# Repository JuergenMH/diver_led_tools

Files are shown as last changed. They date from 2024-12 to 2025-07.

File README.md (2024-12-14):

# diver_led_tools
This repository contains two projects or units.

The first one is a LED "Diver marker" and the second one is "Diver flasher".
Both devices are tools for scuba drivers.
It shares some ressources, this was the reason to put them into one repository.

## Folders
    2D drawings:            brainstorming folder with ideas how to create possible water proofed housings for the diver marker/flasher.
    documents:              different documents regarding both units.
    Firmware_diver_flasher: currently a copy of an older project which will be the base for the new software
    FIrmware_diver_marker:  ditto
    Pcb_Diver_Marker:       Eagle (7.6) PCB for this unit
    Pcb_Diver_Flasher:      KiCAD (8.0) PCB for this unit
    SKEDD-PIC-Cable:        KiCAD (8.0) schematic for the connection cable PICKIT <> PCB for program and debug purposes

## Current state (14.12.2024)
The folder structures and content are still under construction!

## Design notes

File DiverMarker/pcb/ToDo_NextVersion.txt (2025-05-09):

+/- der LEDs sind aktuell vertauscht und teilweise auf falschen Layern

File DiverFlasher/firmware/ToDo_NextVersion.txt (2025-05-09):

MOSFET 2mm in Richtung Batteriehalter schieben
Auf Unterseite + und - im Ausschnitt des Batteriehalters auf den Bottom Silkscreen
Beim Spulen-Footprint die Pads ca. 2mm nach außen setzen (leichtere Lötbarkeit)

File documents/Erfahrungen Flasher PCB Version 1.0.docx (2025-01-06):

# Erfahrungen mit der ersten PCB-Version

## Funktion

Die Leiterkarte funktioniert grundsätzlich, aber die emittierte Lichtmenge ist nicht überzeugend.

Die 5V-Spannung zur Versorgung der LEDs bricht beim Blitz auf einen Wert von ca. 4,5V ein und der LED-Strom liegt um 350mA an Stelle der erwarteten 1A.

Achtung: Im Schaltplan waren 1W LEDs eingetragen. Es gibt sie in der gleichen Bauform auch als 3W Typen. Zu prüfen ist, was bestellt und was demzufolge bestückt wurde.

Das hat zwei Ursachen:

1. Die im Pufferkondensator (470µF) gespeicherte Energie reicht bei weitem nicht aus, die erforderlichen 50ms zu puffern. Selbst bei einer parallelgeschalteten Kapazität von 1000µF ergibt sich keine deutliche Verbesserung. => Erhöhung der Kapazität nicht erfolgversprechend.
2. Der Boost-Konverter liefert nur einen Strom von ca. 0,5 A und das reicht nicht aus, um die Spannung am Ladekondensator zu halten. Reicht noch nicht einmal für 1W LEDs …

Folgende Maßnahmen wurde erfolglos geprüft:

- Erhöhung der Booster-Spannung auf 6V => messbare, aber nicht sichtbare Wirkung
- 1Ohm LED-Vorwiderstand reduziert über 0,33, 0,18 auf 0Ohm (420mA) => schwacher Effekt sichtbar.
- Verlängerung der Blitzdauer auf 75ms => schwacher Effekt sichtbar Darüber hinaus wird der Blitz länger, aber nicht heller

Fazit: Die Schaltung muss überarbeitet werden!

## Library/Footprints

Beim Batteriehalter haben die Bohrungen der beiden dicken Bolzen einen viel zu kleinen Durchmesser; beim Prototyp wurden 3,5mm gebohrt; das hat funktioniert.Es gibt noch einen dritten Bolzen, der ein Verdrehen verhindert. Dieser Bolzen fehlt komplett.

Für die Elkos wurden falsche Footprints ausgewählt.

Fazit: Footprint Batteriehaltermuss korrigiert werden!
Für die Elkos Footprint „eine Nummer größer“ wählen

## Sonstige Themen

Der Batteriehalter ist für ungeschützte 18650 Zellen ausgelegt; bestellt wurden aber geschützte Zellen. Diese sind ca. 3mm länger, als ungeschützte und passen nur mit Gewalt in den Halter.

- Ungeschützte Zellen bestellen

Der SKEDD-Stecker kann nicht eingesteckt werden, wenn die Batterie vollständig in den Halter eingelegt ist. Nicht perfekt, aber akzeptabel.

- Nicht perfekt, aber akzeptabel

Die 470µF Elkos bauen relativ hoch auf. Zwei Optionen sind denkbar: Mehrere kleinere Kondensatoren parallel oder die „dicken“ LEDs auf die Seite der Batterie verlegen. In diesem Fall wird die Platine größer.
Allerdings: Wenn eine Seite der Platine flach gestaltet würde, und die Platine nicht in der Mitte des Gehäuses säße, wären auch die LEDs nicht mehr in der Mitte der Lichtkuppel => macht wenig Sinn.

- Bei den Arbeiten am Booster, dieses Thema bearbeiten; keine hohe Priorität.

Zusammenfassung / Übersicht über die Punkte:

- LEDs sind möglicherweise falsch; geplant waren 3W; eingesetzt wurden ggf. nur 1W LEDs
- Geschützte Batterie passt nicht gut in die Fassung
- Die erste Schaltung bringt rund 2*1W und das ist nicht sonderlich hell
- Vermutlich wäre ein mit 3,3V schaltender N-MOSFET günstiger als der gewählte NPN-Darlington.

Mögliche Lösungen:

Ende des Dokuments.

PCB Diver Flasher Version 1.0

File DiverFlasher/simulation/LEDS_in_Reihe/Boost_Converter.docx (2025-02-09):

Kurvenformen

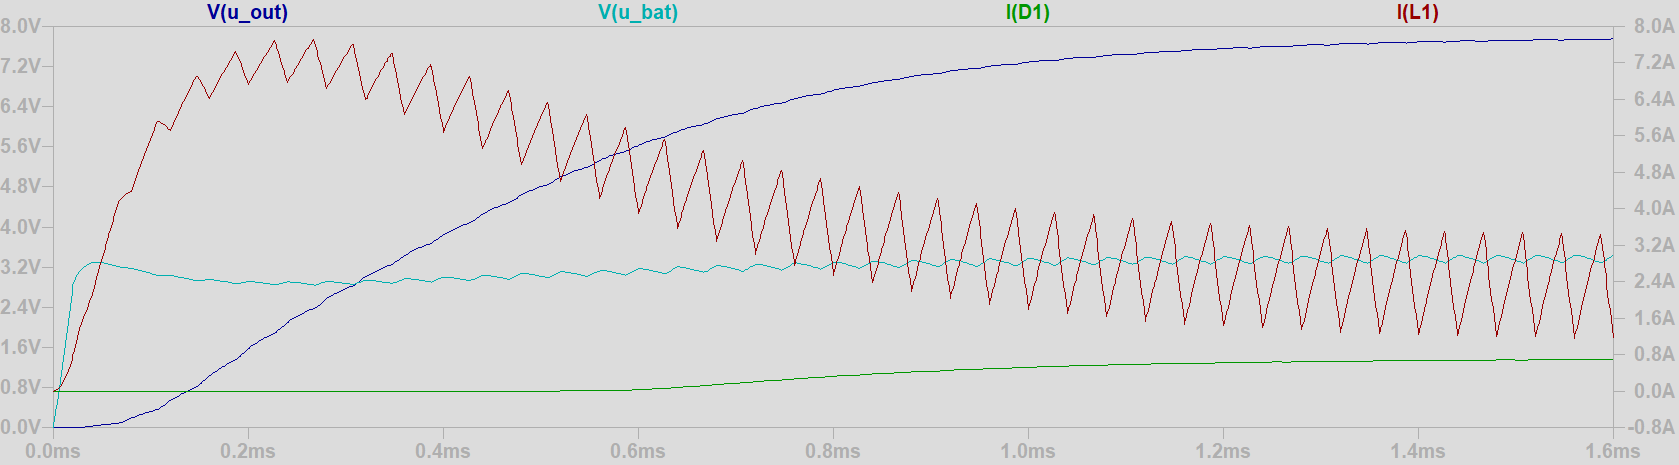
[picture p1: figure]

Schaltung

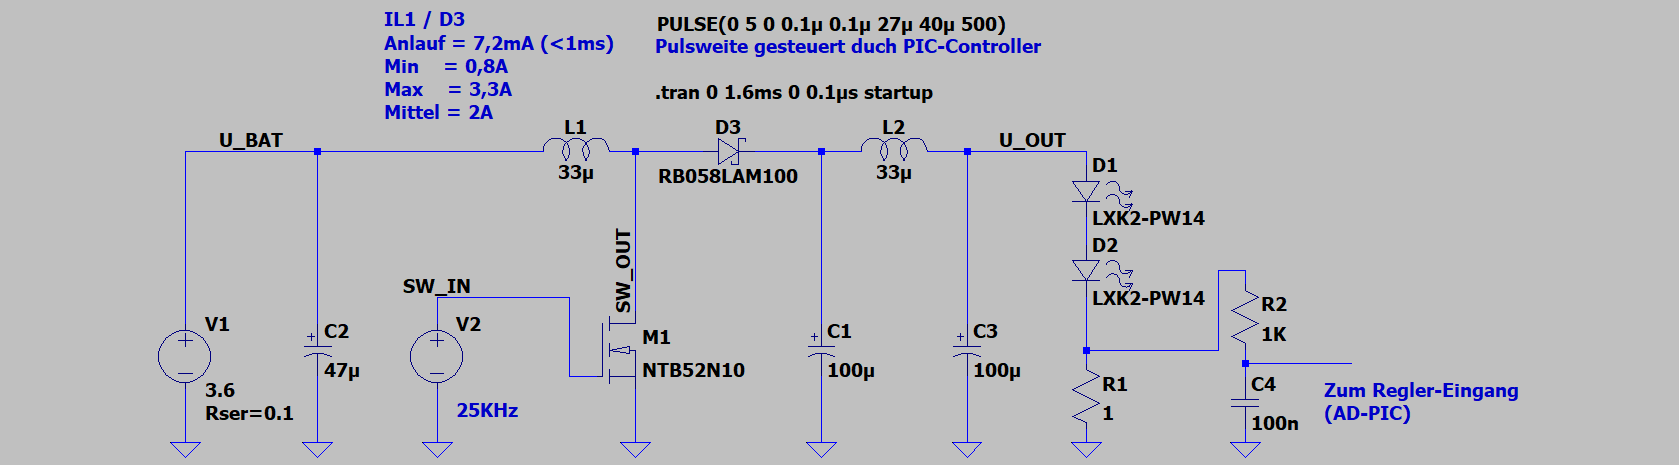
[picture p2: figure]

Boost Converter mit LEDs in Reihe

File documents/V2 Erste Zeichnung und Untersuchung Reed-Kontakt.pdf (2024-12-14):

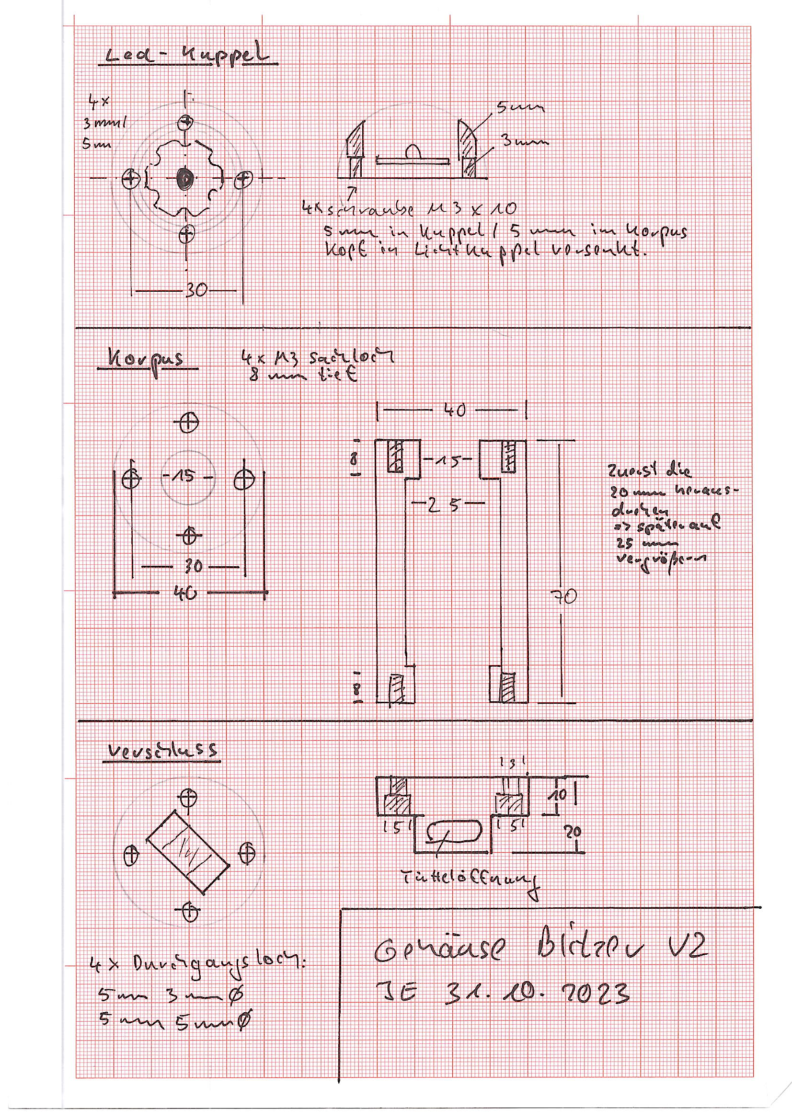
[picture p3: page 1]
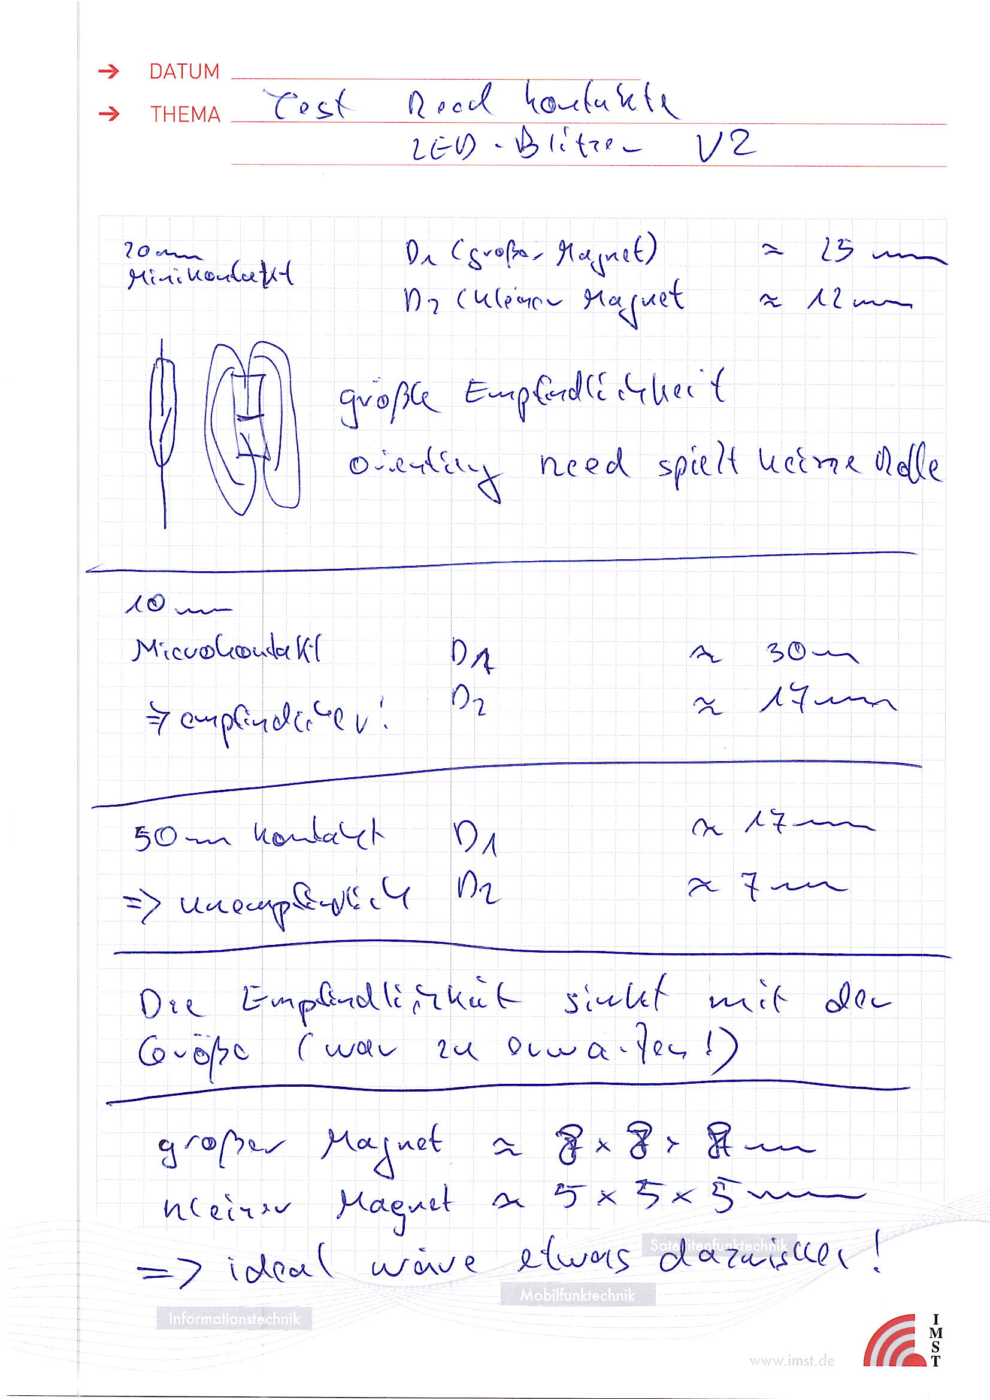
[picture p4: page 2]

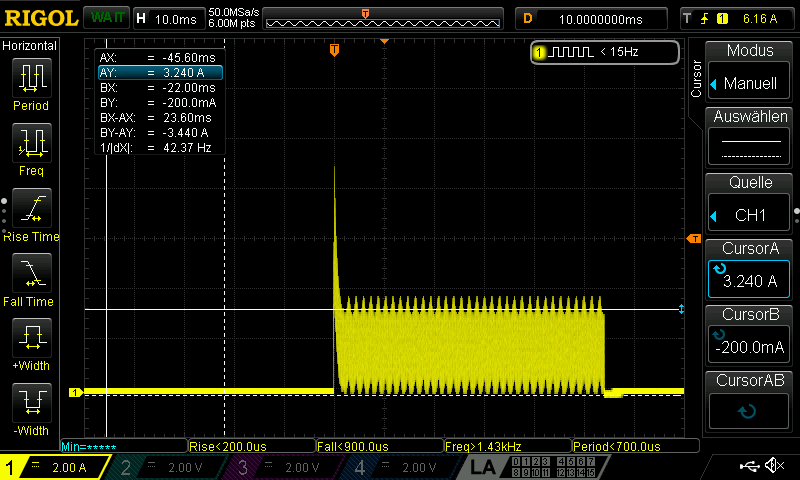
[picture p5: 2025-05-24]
DiverMarker/documents/Stromaufnahme beim EInschalten der LED.png

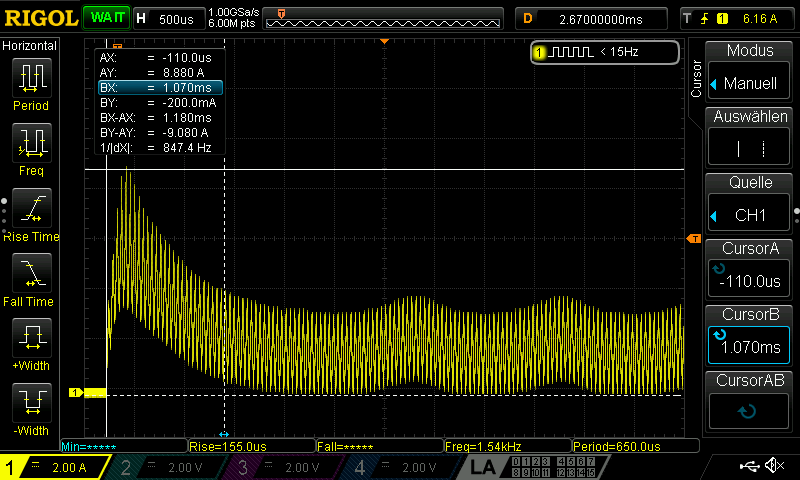
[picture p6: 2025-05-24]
DiverFlasher/documents/Dynamischer Stromverlauf beim Anlaufen des Boost-Reglers.png

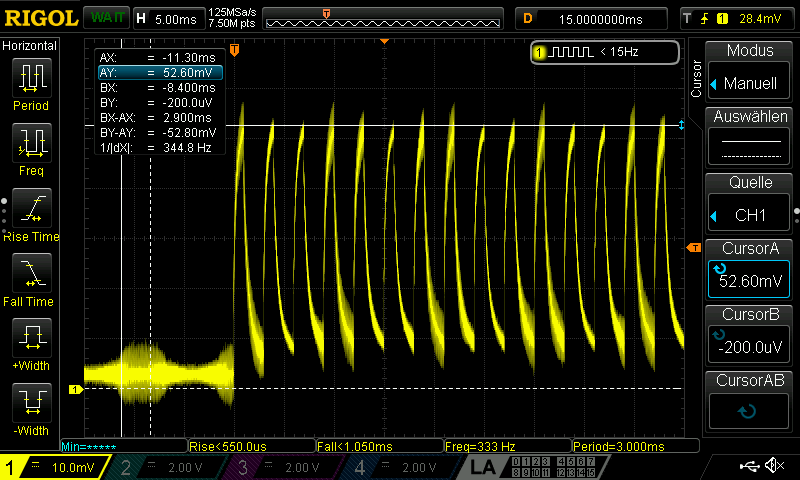
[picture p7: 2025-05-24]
DiverMarker/documents/Stromaufnahme bei 33Prozent PWM der LEDs.png

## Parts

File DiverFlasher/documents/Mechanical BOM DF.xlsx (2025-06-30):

Mechanical BOM "Diver Flasher"
Component | Count | Material | Dimensions | Source | Price 1) | Order number or link | Remark
Main clear tube | 1 | PMMA (Acryl) or Polycarbonat | Outer 40mm, Inner 36mm, Length xx mm | TBD
O-Ring | 4 | Nitril | 34mm x 27mm x 3.5mm | Amazon | 0.40 € | https://www.amazon.de/dp/B0BZP987WF | Package with 10 o-rings
Eyebolt | 1 | V2A or better | M& * 11mm | Amazon | 1.80 € | https://www.amazon.de/dp/B08LQSQQWM | Package with 6 pieces
Wing screw | 1 | V2A or better | M4 * 10mm | Amazon | 0.40 € | https://www.amazon.de/dp/B07TWG3KTY | Package with 30 pieces

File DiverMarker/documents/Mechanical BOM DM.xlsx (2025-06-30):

Mechanical BOM "Diver Marker"
Component | Count | Material | Dimensions | Source | Price 1) | Order number or link | Remark
Main clear tube | 1 | PMMA (Acryl) or Polycarbonat | Outer 32mm, Inner 26mm, Length xx mm | Amazon | 2.50 € | https://www.amazon.de/dp/B0DS7PPN5B | Package with 4 tubes => 8 devices
O-Ring | 4 |  | 25mm x 18mm x 3.5mm | Amazon | 0.25 € | https://www.amazon.de/gp/product/B0BZP2CDTC | Package with 20 O-rings
Eyebolt | 1 or 2 | V2A or better | M5 * 11mm | Amazon | 1.00 € | https://www.amazon.de/dp/B0CZ8L6CKB | Package with 8 pieces
Wing screw | 1 | V2A or better | M3 * 10mm | Amazon | 0.33 € | https://www.amazon.de/gp/product/B07TXFYQLT | Package with 30 pieces
1) price about one component

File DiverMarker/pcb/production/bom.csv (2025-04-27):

Designator | Footprint | Quantity | Value | LCSC Part #
BT101 | BatteryHolder_Keystone_2460_1xAA | 1 | Keystone 2460
C105 | 0805 | 1 | 100nF
C107, C108 | CP_Elec_6.3x5.8 | 2 | 100µF/16V
D101 | D_SOD-123 | 1 | BAV16W
D103 | LPB200XX | 1 | LB-P200B2C-H, blue
D104 | LPB200XX | 1 | LB-P200G3C-H, green
IC101 | SSOP-8_3.9x5.05mm_P1.27mm | 1 | PIC16LF15313
J101 | SKEDD-6 | 1 | SKEDD6
Q100, Q101 | SOT-89-3_Handsoldering | 2 | BST-52
R101, R106 | 0805 | 2 | 10K
R102, R109, R110 | 0805 | 3 | 1K
R103, R107 | 1206 | 2 | 2,2
R104, R108 | 0805 | 2 | 100K
SW101 | Meder MK15-C-2 | 1 | MK15-C2
TP101, TP102, TP103, TP104, TP106 | TestPoint_Pad_D1.5mm | 5 | TestPoint

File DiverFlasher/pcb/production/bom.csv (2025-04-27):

Designator | Footprint | Quantity | Value | LCSC Part #
BAT101 | BatteryHolder_Keystone_1042_1x18650 | 1 | KEYSTONE Battery Holder 1042
C102, C105, C106 | 0805 | 3 | 100nF
C103, C104, C107, C108 | CP_Elec_6.3x5.8 | 4 | 100µF/16V
D101 | D_SOD-123 | 1 | BAV16W
D102 | D_SMC_Handsoldering | 1 | SL42
D103, D104 | LPB200XX | 2 | LB-P200W2C-H3
IC101 | SSOP-8_3.9x5.05mm_P1.27mm | 1 | PIC16LF15313
J101 | SKEDD-6 | 1 | SKEDD6
L101, L102 | L_12x12mm_H8mm | 2 | 33µH
R101, R106 | 0805 | 2 | 10K
R102, R104 | 0805 | 2 | 1K
R103 | 1206 | 1 | 1
R105 | 0805 | 1 | 100K
SW101 | Meder MK15-C-2 | 1 | MK15-C2
T101 | TO-220-3_Vertical | 1 | DMT6009LCT
TP101, TP102, TP103, TP104, TP105, TP106 | TestPoint_Pad_D1.5mm | 6 | TestPoint

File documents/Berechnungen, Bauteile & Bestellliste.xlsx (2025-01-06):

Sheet: Bestelliste
Komponente | Wert | Anwendung | Distributor | Bestellnummer | Preis | Bestellt | Anmerkung
T100, T101 | BST52TA | Schalttransistor für LED | Reichelt | BST 52 SMD | 0.64 € | 10 | 80V, 1A, Darlington NPN
R101, R102 | 0,33 Ohm 0805 | Strombegrenzung SMD-Version | Reichelt | PAN ERJ6BQFR33V | 0.62 € | 10 | Ab 10 Stück 0,403€
BATT100 | HA 18650 EK | Für Flasher mit 18650 | Reichelt | HA 18650 EK | 0.84 € | 6 | Einzelkontakt für Eine Batterie werden 2 benötigt
BATT100 | Halter AA | Für Diver Marker Batterie | Reichelt | KEYSTONE 1024 | 3.50 € | 2 | Halter für AA Batterie SMD
C101, C102 | 220µF / 10V | Puffer für LED-Strom | Reichelt | FK 470/10 AP | 0.61 € | 6 | Panasonic, Gehäuse D8
C103 | 100µF / 10V | Puffer für Elektronik | Reichelt | HD-V 100U 10 | 0.46 € | 6
D100, D101 | LB-P200W2C60 | Für LED Blitzer | Reichelt | LB-P200W2C60 | 1.10 € | 6 | Standard
D100 | LB-P200B2C-H | Für LED Diver Marker, blau | Reichelt | LB-P200B2C-H | 0.95 € | 6 | Alternative Anwendung
D101 | LB-P200G3C-H | Für LED Diver Marker, grün | Reichelt | LB-P200G3C-H | 0.95 € | 6 | Alternative Anwendung
D102 | BAS40 | Entkopplung Elektronik | Reichelt | BAS 40 NXP | 0.09 € | 20 | Gibt es von verschiedenen Herstellern
IC100 | PIC 16LF1559-ISS | Alternativer Controller | Reichelt | PIC 16LF1559-ISS | 1.50 € |  | PIC16LF1554/1559, 20 Pin
n/a | 18650 Akku | Hauptbatterie Flasher | Reichelt | SON 18650 VTC5A XTAR 18650-2600 | 16,99 7,41 | 3 | Paket mit zwei Stück Panasonic aktuell nicht lieferbar…
n/a | Batterie AA | Hauptbatterie Diver Marker | Reichelt | ANS 1522-0036-1 | 4.99 € | 2 | Paket mit zwei Stück
IC100 | PIC16LF15313-I/P | Steuercontroller | n/a | PIC16LF15313 |  |  | SMD an Lager (2 Stück)
 |  |  |  |  |  |  | writ

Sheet: Flasher
Untersuchung: Möglichkeiten einer höheren Versorgungsspannung
Messung 1: Zusammenhang Widerstand - Strom
Vorwiderstand in Ohm | Versorgungs- spannung in V | Spannung Widerstand in V | Strom in A | Leistung in W | Anmerkung | Für Grafik | I@3Ohm | I@2Ohm | I@1Ohm
3 | 3.6 | 0.225 | 0.075 | 0.255 |  | 3.6 | 0.075 | 0.125 | 0.137
 | 4.5 | 0.800 | 0.267 | 0.907 |  | 4.5 | 0.267 | 0.320 | 0.548
 | 5.0 | 1.100 | 0.367 | 1.247 |  | 5.0 | 0.367 | 0.510 | 0.832
 | 5.5 | 1.200 | 0.400 | 1.360 |  | 5.5 | 0.400 | 0.685 | 1.210
2 | 3.6 | 0.250 | 0.125 | 0.425
 | 4.5 | 0.640 | 0.320 | 1.088
 | 5.0 | 1.020 | 0.510 | 1.734
 | 5.5 | 1.370 | 0.685 | 2.329
1 | 3.6 | 0.137 | 0.137 | 0.466
 | 4.5 | 0.548 | 0.548 | 1.863
 | 5.0 | 0.832 | 0.832 | 2.829 | Achtung: > 800mA
 | 5.5 | 1.210 | 1.210 | 4.114 | Achtung: > 800mA
Messung : Strom bei Spannungsverdoppler 7,2V
Vorwiderstand in Ohm | Versorgungs- spannung in V | Spannung Widerstand in V | Strom in A | Leistung in W | Anmerkung
3 | 72.0 | 2.760 | 0.920 | 3.128 | Achtung > 800mA und > 3W
Es ist leicht; größere Leistungen zu erreichen; vermutlich aber auf Kosten höherer Verluste
Ergebnis: Wandler auf 5V und ggf. Feintuning über Vorwiderstand etwas kleiner als 1 Ohm
Achtung: Der BST 52 kann nur 500mA!
Mögliche Schalttranistoren
2STBN15D100 | 0.80 € | 12A | 100V | D2PAK
MJD122T4 | 0.48 € | 8A | 100V | DPAK
Actung: UCE bis zu 2V => Strom nicht reproduzierbar!
Siehe dazu auch Tab "Transistoren"

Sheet: Transistoren
Optimierungsansatz ohne Flasher
 |  |  |  | Mögliche Typen | Umax | Imax | RDSOn | Opt VGS | Gehäuse | Hersteller | Mouser Nummer | Preis
 |  |  |  | DMT8008LFG | 80V | 38A | 10mOhm @4,5V VGS | 5V | PowerDI®3333-8 | Diodes Incorporated | 621-DMT8008LFG-7 | 1.27 €
Betrachtungen Spannungsverlust Schalttransistor |  |  |  | RFD16N05LSM | 50V | 16A | 47mOhm @ | 5V | DPAK-2 (TO−252AA) | Onsemi | 512-RFD16N05LSM9A | 1.12 €
Bezeichnung | MJD122T4 (PCB) | 2N6386 (PB 1) | IRF540N (PB 2) | HUF76629D3ST-F085 | 100V | 20A | 52mOhm @ | s.u.r. | DPAK-2 (TO−252AA) | Onsemi | 512-HUF76629D3ST | 2.20 €
UCE , bzw. UDS [V] | 0.85 | 2.00 | 0.10 | NDB5060L | 60V | 26A | 70mOhm @3,3V | s.u | DPAK-2 (TO−252AA) | Onsemi | 512-NDB5060L | 2.59 €
=> Es darf kein Bipolartransistor verwendet werden!

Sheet: Batterien & Akkus
Link | https://www.reichelt.de/reicheltpedia/index.php/Li-Ion-Akku
Größe 16340 wäre interessant, ist aber nicht zu finden. Alternative wären Li/Po Akkus siehe nächste Seite
Typ | Technologie |  | Nomalspannung | Kapazität [mAh] | Preis | Bild | Link
EEMB Akku 953450 | Li/Po |  | 3,7V | 1800 | 13.00 € |  | https://www.amazon.de/EEMB-953450-wiederaufladbarer-Lithium-Polymer-Akku-Li-Polymer-Akku/dp/B095VQRW73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
EEMB Akku 603449 | Li/Po |  | 3,7V | 1100 | 10.99 |  | https://www.amazon.de/EEMB-Batterien-Stecker-Stellen-Polarit%C3%A4t-%C3%BCbereinstimmt/dp/B08FD39Y5R
Beide sind in etwas gleich groß, aber unterschiedlich dick!
Batterie | Distributor | Maße | Bestellnummer | Preis | Kapazität | Anmerkung
CR2 | Reichelt | D=15,3, L=26,5mm | 070CR2EC1 | 3.70 € | 750 | Würde Halter benötigen
VARTA CR 1/2AACD | Reichelt | D=14,5, L=25,3mm | VARTA CR 1/2AACD | 4.50 € | 950 | Axiale Drähte
Varta CR124 | Reichelt | D=17, L=34,5mm | VARTA CR 123A SP | 2.05 € | 1430 | Würde Halter benötigen Preis bei 10 Stück
Ansmann AA | Reichelt | D=14, L=50mm | ANS 1522-0036-1 | 2.50 € | 2700 | Preis bei 2 Stück (4,99€)

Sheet: LEDs
Diver marker
Diver flasher

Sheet: wo Booster
LED Spannung @750mA
Min | 3.5 | V
Max | 4.0 | V
Batteriespannung @0,5C *
Umin @ Ladestand 20% | 3.6 | V
Umax bei Ladestand 100% | 4.1 | V
*0,5 C, da Kapazität 2,6Ah und Entladestrom ca. 1,5A
=> Ein stabiler Betrieb ist ohne Booster nicht möglich

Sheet: Prüfung Bauteilgrößen
Nummer | Typ Plan | Typ Platine | An Lager | Distri | Pinning
D201 | RS2K | SMB
C101, C102 | 22µF/10V | C/6032-28R |  | Reichelt
C100 | 100nF | C0805
R100 | 10K | R805
R101 | 0,33Ohm | R805
R102 | 1K | R805
T100 | BST52 | SOT89 |  | Reichelt
S100 | MK 15 C2 | MK 15 C2 |  | Reichelt

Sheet: Nebenrechnungen
 | Abhängigkeit Widerstand / Strom |  |  |  |  | Berechnung Batterielebensdauer Flasher (Akku)
 | Widerstand | Einheit | Strom | Einheit | Anmerkung | 18650 | 2600 | mAh | Reichelt am günstigsten
 | 0.33 | Ohm | 0.28 | Ampere | Für Flasher vermutlich zu gering | Strom durch LED | 1.5 | A | für 2 * 3W LED
 | 1 | Ohm | 0.124 | Ampere |  | Ruhezeit | 2 | s | Booster lädt, LEDs sind aus
 | 2 | Ohm | 0.075 | Ampere |  | Aktive Zeit | 50 | ms | LEDs sind an
 | 3 | Ohm | 0.06 | Ampere | Gewählt wg. Batterielaufzeit | Einschaltzeit | 5 | %
 |  |  |  |  |  | Mittlerer Strom | 0.075 | A | LED Strom ohne Verluste
 | Berechnung Batterielebensdauer Diver Marker (Akku) |  |  |  |  | Vor Booster | 0.09375 | A | Annahme 80% Wirkungsgrad
 | 18650 | 2600 | mAh |  |  | Grundstrom | 0.03 | A | CPU, Booster, etc
 | 17500 | 1100 | mAh |  |  | Mittlerer Strom | 0.12375 | A | ca. 0,5W
 | Strom | 0.12 | A |  | In der aktiven Phase 2 * 75mA | Bedarf / h | 0.12375 | Ah | Verbrauch pro Stunde
 | Einschaltzeit | 5 | % |  | Über alles | Betriebsdauer 1 | 21.01010101 | h | … reicht für den Tauchurlaub
 | Grundstrom | 0.01 | A |  | geschätzt für CPU etc. | Hier muss der Akku natürlich im Sockel sitzen
 | Mittlerer Strom | 0.016 | A |  | … fast nichts
 | Bedarf / h | 0.016 | Ah |  | dito
 | Betriebsdauer 1 | 162.5 | h |  | Für 18650
 | Betriebsdauer 2 | 68.75 | h |  | Für 17500
 | Ein Akku macht keinen Sinn; Batterie ist OK
 | Berechnung Batterielebensdauer Diver Marker (Batterie) |  |  |  |  | Leistung Vorwiderstand LED Flasher
 | CR2/AA | 950 | mAh |  | Reichelt am günstigsten
 | CR123 | 1430 | mAh |  | Reichelt 10´er Pack | Vorwiderstand | 0.33 | Ohm
gewählt => | AA | 2750 | mAh |  | Reichelt Ansmann 2´er Pack | Strom angenommen | 0.3 | A
 | Strom | 0.15 | A |  | In der aktiven Phase 2 * 75mA | Dauer on | 50 | ms
 | Einschaltzeit | 5 | % |  | Über alles | Pause | 1000 | ms
 | Grundstrom | 0.01 | A |  | geschätzt für CPU etc. | Einschaltzeit | 5 | %
 | Mittlerer Strom | 0.0175 | A |  | … fast nichts | Mittlerer Strom | 0.015 | A
 | Bedarf / h | 0.0175 | Ah |  | dito | Leistung gemittelt | 7.425e-05 | W
 | Betriebsdauer 1 | 54.28571429 | h |  | CR2/AA | Spitzenleistung bei Dauerbestromung | 0.0297 | W
 | Betriebsdauer 2 | 81.71428571 | h |  | CR123 | Leistung Widerstand 0805 | 0.15 | W
 | Betriebsdauer 2 | 157.1428571 | h |  | AA | Leistung Widerstand 0603 | 0.1 | W
 | Die größte Batterie würde ca. 2 Jahre halten … Einlöten macht aber keinen Sinn. |  |  |  |  | 0805 oder 0603 sind vollkommen in Ordnung
 |  |  |  |  |  | Aber: Lichtleistung zu gering!

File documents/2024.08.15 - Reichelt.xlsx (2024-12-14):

Schalttransistor für LED | Reichelt | BST 52 SMD | 0.64 € | 10 | 80V, 1A, Darlington NPN
Strombegrenzung SMD-Version | Reichelt | PAN ERJ6BQFR33V | 0.62 € | 10 | Ab 10 Stück 0,403€
Für Flasher mit 18650 | Reichelt | HA 18650 EK | 0.84 € | 6 | Einzelkontakt für Eine Batterie werden 2 benötigt
Für Diver Marker Batterie | Reichelt | KEYSTONE 1024 | 3.50 € | 2 | Halter für AA Batterie SMD
Puffer für LED-Strom | Reichelt | FK 470/10 AP | 0.61 € | 6 | Panasonic, Gehäuse D8
Puffer für Elektronik | Reichelt | HD-V 100U 10 | 0.46 € | 6
Für LED Blitzer | Reichelt | LB-P200W2C60 | 1.10 € | 6 | Standard
Für LED Diver Marker, blau | Reichelt | LB-P200B2C-H | 0.95 € | 6 | Alternative Anwendung
Für LED Diver Marker, grün | Reichelt | LB-P200G3C-H | 0.95 € | 6 | Alternative Anwendung
Entkopplung Elektronik | Reichelt | BAS 40 NXP | 0.09 € | 20 | Gibt es von verschiedenen Herstellern
Hauptbatterie Flasher | Reichelt | XTAR 18650-2600 | 7.41 € | 3 | Panasonic aktuell nicht lieferbar…
Hauptbatterie Diver Marker | Reichelt | ANS 1522-0036-1 | 4.99 € | 2 | Paket mit zwei Stück
Prozessor für MBC2 | Reichelt | Z84C00-10MHZ | 10.95 € | 1 | 10MHz günstiger als 8
Hilfsprozessor | Reichelt | ATMEGA32A-PU | 4.95 € | 1
NAND | Reichelt | 74HC 00 | 0.24 € | 1
RAM | Reichelt | 628128-70 M | 2.70 € | 1

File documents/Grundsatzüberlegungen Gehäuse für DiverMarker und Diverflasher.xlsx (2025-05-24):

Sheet: Grundmaße
Grundsätzliche Daten PCB
 | Diver Flasher | Diver Marker
PCB-Gesamtlänge | 105 | 75
PCB Breite | 24 | 20
Versenkbar *) | 6 | 7
Erf. Durchmesser | 31 | 25
*) Teil der Platine, der im Boden eingesteckt werden kann
Alle angegebenen Maße in mm

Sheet: Rohre
Mögliche Rohre und Kappen
 |  |  |  |  |  |  |  | für Diver..
Material | Außen | Innen | Wandstärke | Preis | Versand | Lämge | Link | Marker | Flasher | Anmerkung
PVC transluszent | 32 | 28.4 | 1.8 | 12.99 € |  | 1m | Amazon (https://www.amazon.de/gp/product/B0CWXSHPDL/ref=ox_sc_saved_title_4?th=1) | ja | nein | Wandstärke für Diver Marker ggf. zu gering
PVC transluszent | 40 | 36 | 2 | 14.99 € |  | 1m | Amazon (https://www.amazon.de/gp/product/B0CWXSHPDL/ref=ox_sc_saved_title_4?th=1) | ja | ja | Wandstärke besser; ggf. Reed-Problem bei DM
Acrylglas | 30 | 26 | 2 | 13.95 € |  | 1m | Amazon (https://www.amazon.de/gp/product/B0DCTV2H5W/ref=ox_sc_saved_title_5?th=1) | ja | nein | Wandstärke für Diver Marker ggf. zu gering
Acrylglas | 36 | 32 | 2 | 15.75 € |  | 1m | Amazon (https://www.amazon.de/gp/product/B0DCTV2H5W/ref=ox_sc_saved_title_5?th=1) | ja | ja | ggf. Reed-Problem bei DM
Aluminium | 30 | 26 | 2 | 9.44 € | 6.90 € | 2m | Amazon (https://www.amazon.de/PRIOstahl-Aluminiumrohr-Rundrohr-Alu-Rohr-Profil/dp/B0DL5LFBJH) | ja | nein | 2m lang; unkaputtbar für DM, Versandkosten?
Aluminium 1) | 35 | 31 | 2 | 15.99 € | 6.90 € | 2m | Amazon (https://www.amazon.de/Riggatec-Alu-Rohr-Rund-35x2mm-L%C3%A4nge/dp/B00JJY2JXY) | ja | ja | 2m lang, incl 6,90 Versand
Acrylglasstab (Deckel) | 40 |  |  | 15.49 € | 0.00 € | 2*0,1 | Amazon (https://www.amazon.de/QUARKZMAN-Rundst%C3%A4be-Kunststoff-Beleuchtung-Dekorationen/dp/B0DTKB6J8Z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) |  |  | Deckel für Alum-Rohr
1) ggf Versandkosten sparen, indem alles im Riggatec Shop gekauft wird
https://www.amazon.de/stores/page/709ACE7E-CA6D-4A4A-A73F-255727D0191A/search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
Vorteile ALU
Lieferant GWT für PVC |  |  |  |  |  |  | Amazon (https://www.gwt-versandhandel.de/de/Rohr-Schlauch/pvc-rohr-transparent/) |  |  | Versandkosten 4,90€ pro Bestellung

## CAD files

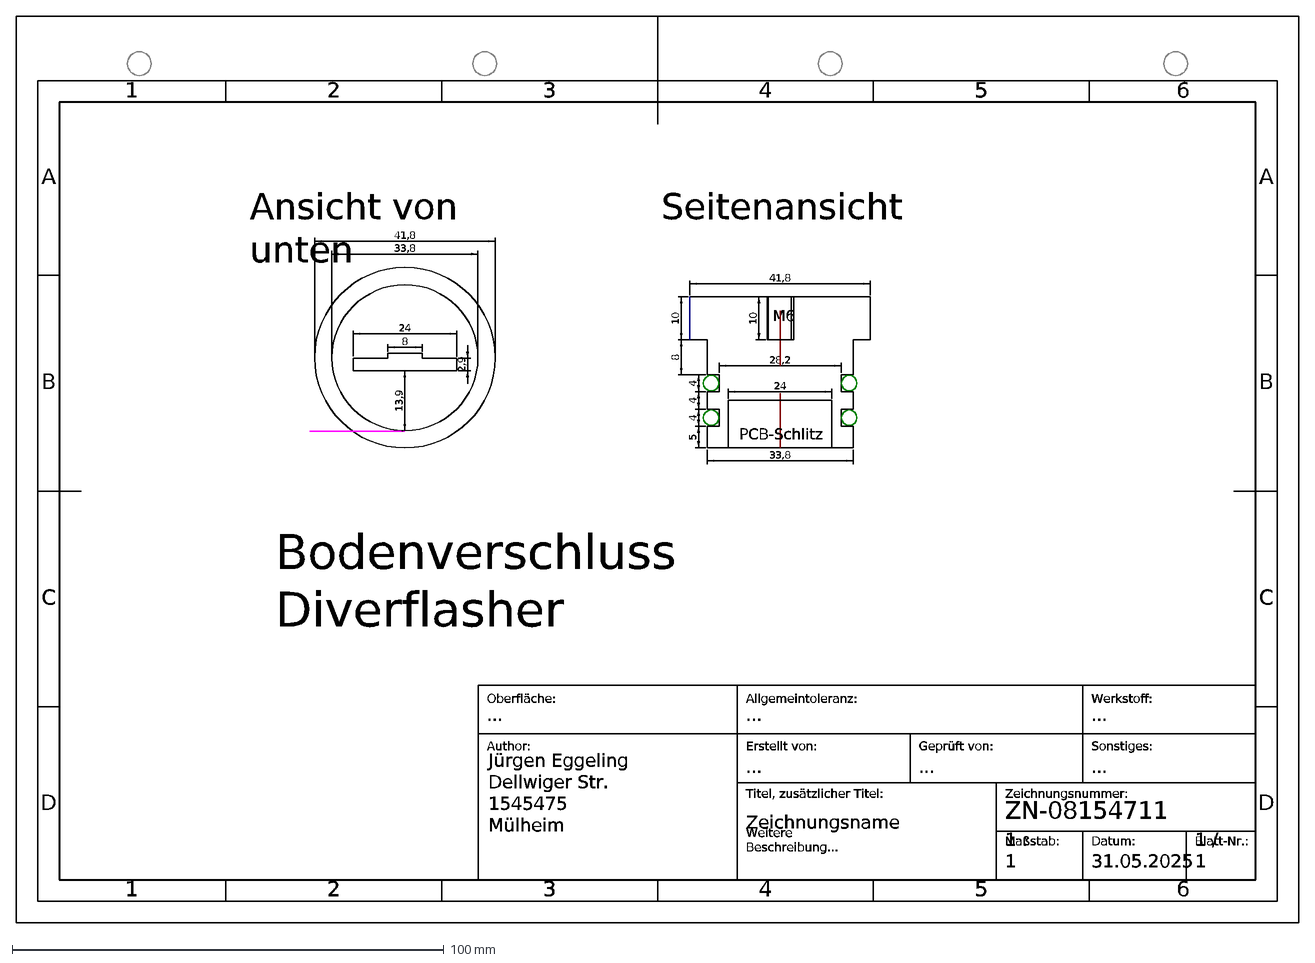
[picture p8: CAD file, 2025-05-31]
DiverFlasher/drawings/Rohrboden.dxf
1
2
A
3
4
5
6
B
C
D
Geprüft von:
Erstellt von:
Zeichnungsnummer:
Titel, zusätzlicher Titel:
Maßstab:
Datum:
Allgemeintoleranz:
Werkstoff:
Oberfläche:
Weitere Beschreibung...
1 : 1
Blatt-Nr.:
1 / 1
Zeichnungsname
...
Sonstiges:
ZN-08154711
31.05.2025
Author:
Jürgen Eggeling Dellwiger Str. 15 45475 Mülheim
33,8
8
10
41,8
28,2
M6
PCB-Schlitz
24
Bodenverschluss Diverflasher
2,9
13,9
Seitenansicht
Ansicht von unten

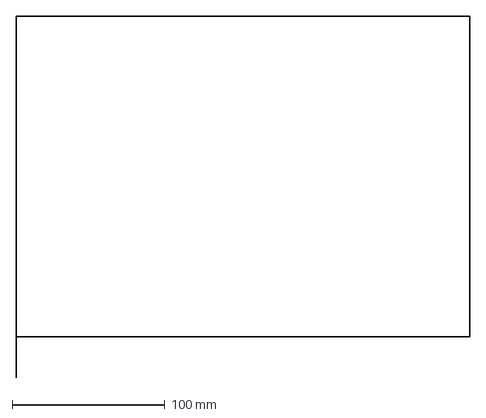
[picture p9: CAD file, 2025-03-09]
DiverMarker/drawings/Frame_A4_quer.dxf
297.0 x 237.0 mm

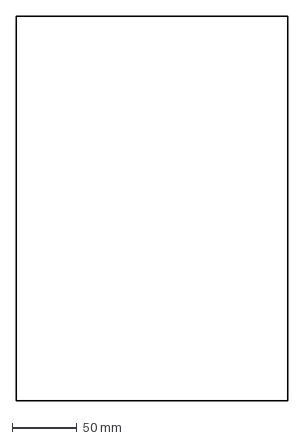
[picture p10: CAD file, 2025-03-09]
DiverMarker/drawings/#Frame_A4_hoch.dxf
210.0 x 297.0 mm

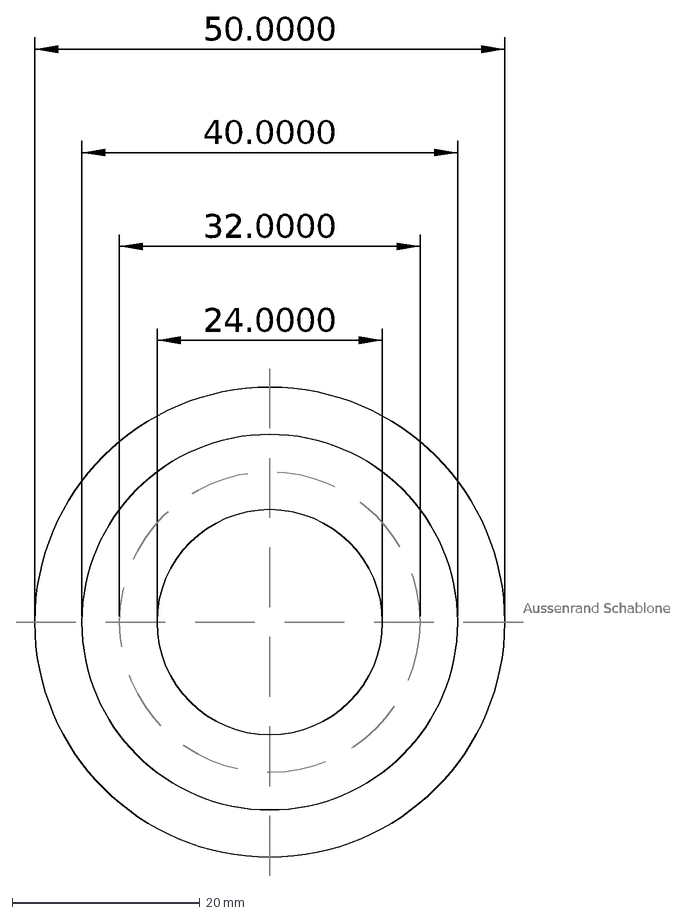
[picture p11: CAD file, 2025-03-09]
DiverMarker/drawings/Bohrschablone.dxf
24.0000
32.0000
40.0000
50.0000
Aussenrand Schablone

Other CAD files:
DiverMarker/drawings/Gehäuse.dxf
DiverMarker/drawings/Frame_A4_hoch.dxf

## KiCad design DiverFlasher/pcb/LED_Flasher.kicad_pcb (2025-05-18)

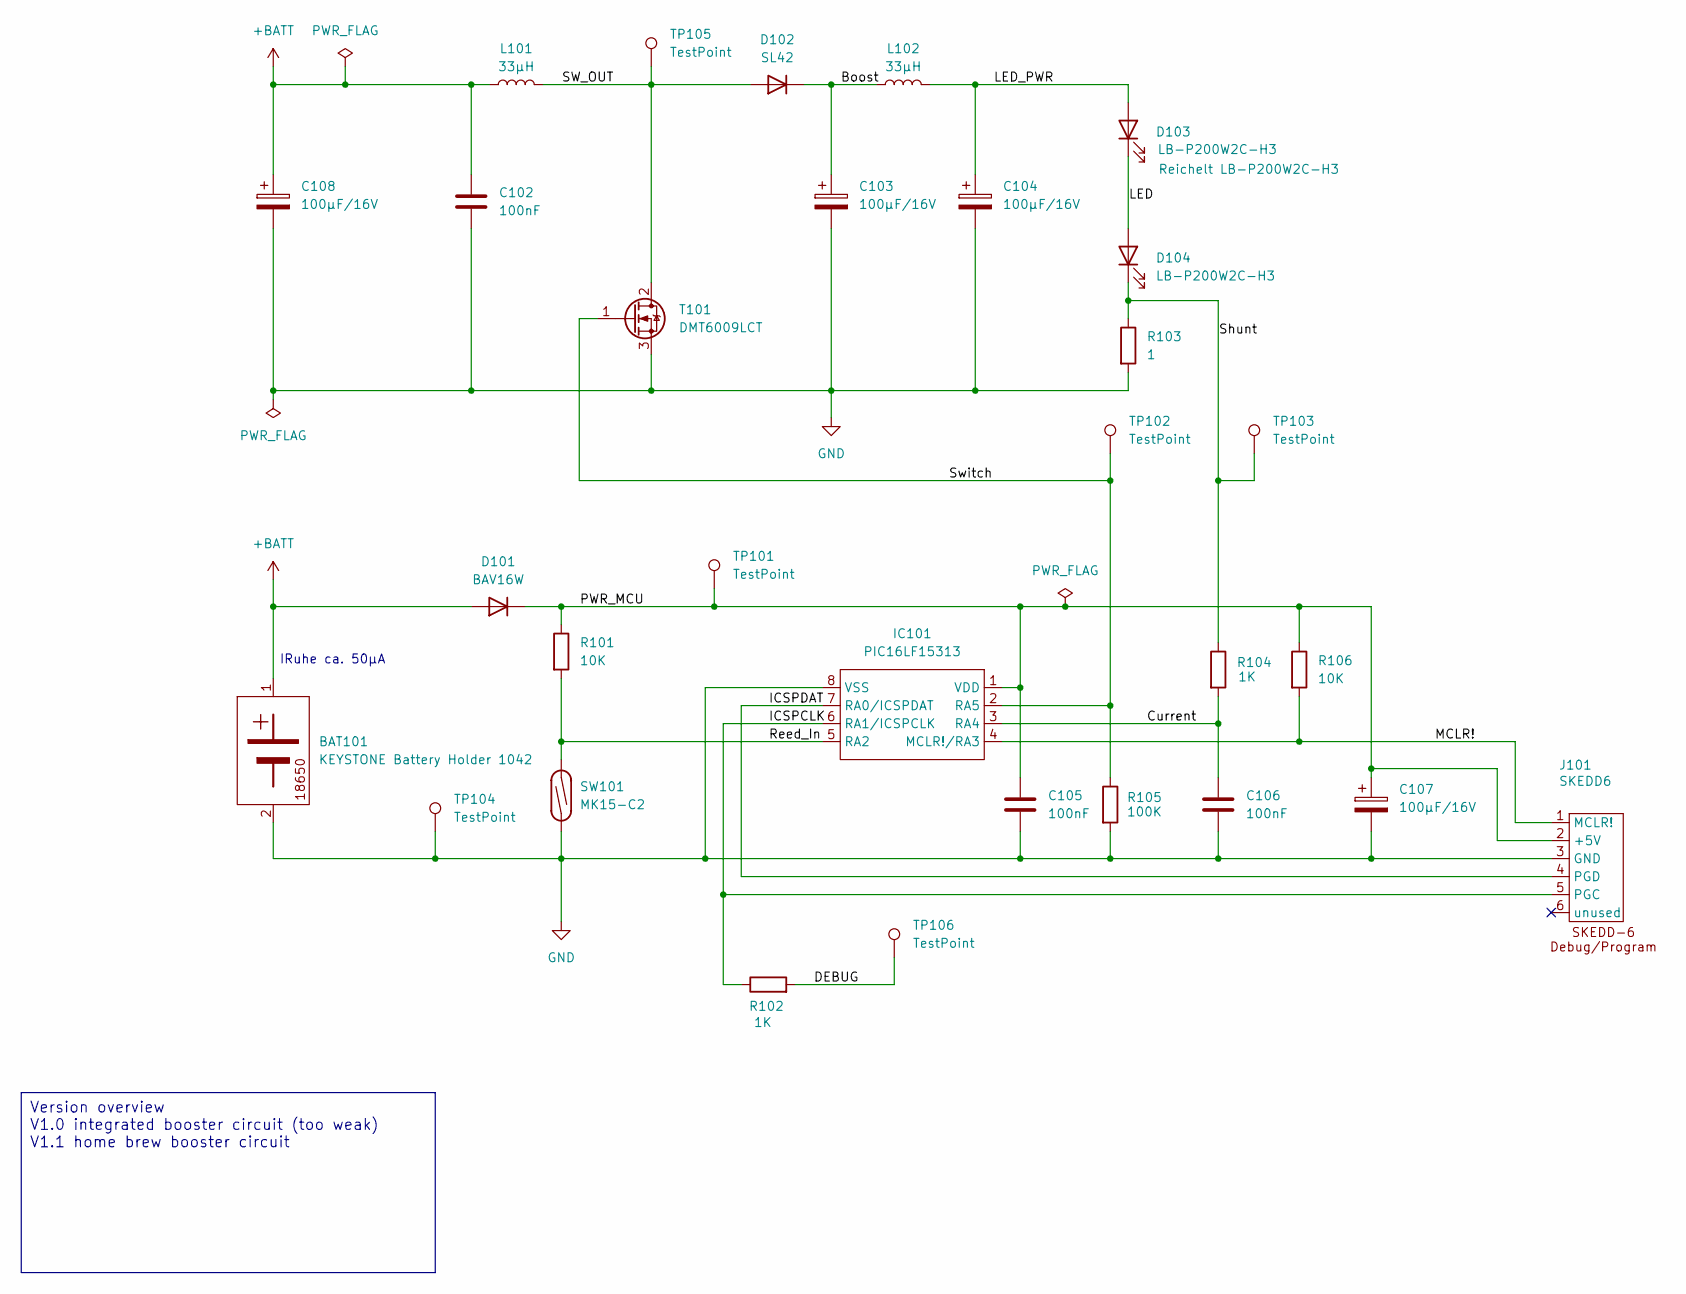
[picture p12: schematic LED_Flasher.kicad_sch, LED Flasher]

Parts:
BAT101: KEYSTONE Battery Holder 1042; BatteryHolder_Keystone_1042_1x18650
C102, C105, C106: 100nF; C_0805_2012Metric_Pad1.18x1.45mm_HandSolder
C103, C104, C107, C108: 100µF/16V; CP_Elec_6.3x5.8
D101: BAV16W; D_SOD-123
D102: SL42; D_SMC_Handsoldering
D103, D104: LB-P200W2C-H3; LPB200XX
IC101: PIC16LF15313; SSOP-8_3.9x5.05mm_P1.27mm
J101: SKEDD6; SKEDD-6
L101, L102: 33µH; L_12x12mm_H8mm
R101, R106: 10K; R_0805_2012Metric_Pad1.20x1.40mm_HandSolder
R102, R104: 1K; R_0805_2012Metric_Pad1.20x1.40mm_HandSolder
R103: 1; R_1206_3216Metric_Pad1.30x1.75mm_HandSolder
R105: 100K; R_0805_2012Metric_Pad1.20x1.40mm_HandSolder
SW101: MK15-C2; Meder MK15-C-2
T101: DMT6009LCT; TO-220-3_Vertical
TP101, TP102, TP103, TP104, TP105, TP106: TestPoint; TestPoint_Pad_D1.5mm

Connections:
+BATT: BAT101.1 (+), C102.1, C108.1, D101.2 (A), L101.1
/Boost: C103.1, D102.1 (K), L102.1
/Current: C106.1, IC101.3 (RA4), R104.2
/DEBUG: R102.2, TP106.1
/ICSPCLK: IC101.6 (RA1/ICSPCLK), J101.5 (PGC), R102.1
/ICSPDAT: IC101.7 (RA0/ICSPDAT), J101.4 (PGD)
/LED: D103.1 (K), D104.2 (A)
/LED_PWR: C104.1, D103.2 (A), L102.2
/MCLR!: IC101.4 (MCLR!/RA3), J101.1 (MCLR!), R106.2
/PWR_MCU: C105.1, C107.1, D101.1 (K), IC101.1 (VDD), J101.2 (+5V), R101.1, R106.1, TP101.1
/Reed_In: IC101.5 (RA2), R101.2, SW101.2
/SW_OUT: D102.2 (A), L101.2, T101.2 (D), TP105.1
/Shunt: D104.1 (K), R103.1, R104.1, TP103.1
/Switch: IC101.2 (RA5), R105.1, T101.1 (G), TP102.1
GND: BAT101.2 (-), C102.2, C103.2, C104.2, C105.2, C106.2, C107.2, C108.2, IC101.8 (VSS), J101.3 (GND), R103.2, R105.2, SW101.1, T101.3 (S), TP104.1

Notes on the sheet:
IRuhe ca. 50µA
Version overview V1.0 integrated booster circuit (too weak) V1.1 home brew booster circuit

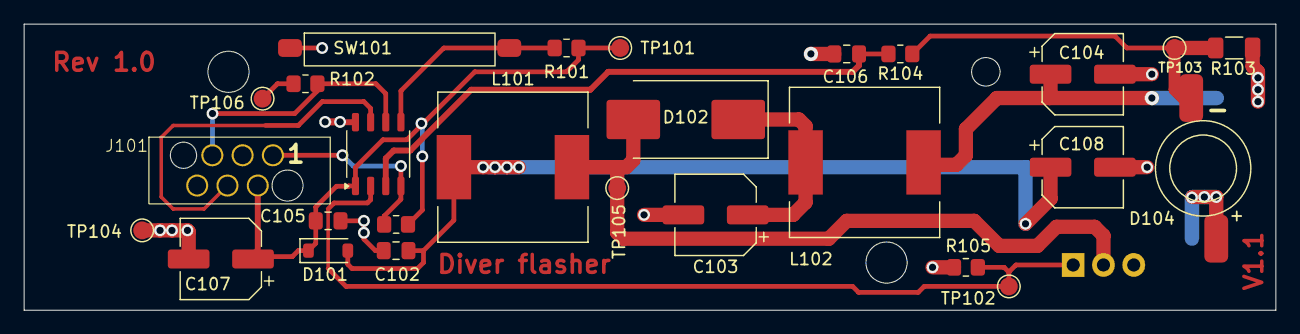
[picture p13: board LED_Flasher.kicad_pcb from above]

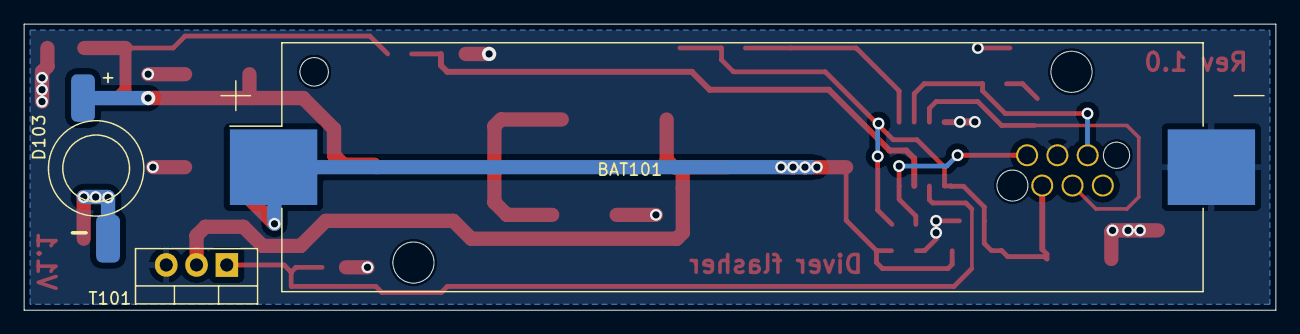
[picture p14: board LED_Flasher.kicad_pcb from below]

Board: 2 copper layers, 105.0 x 24.0 mm, 30 parts (3 on the bottom side), 15 nets.

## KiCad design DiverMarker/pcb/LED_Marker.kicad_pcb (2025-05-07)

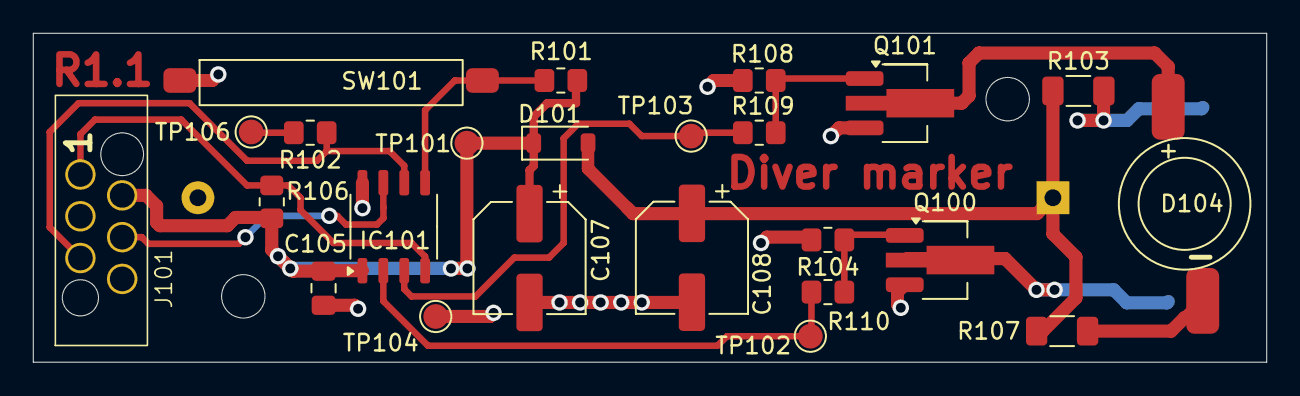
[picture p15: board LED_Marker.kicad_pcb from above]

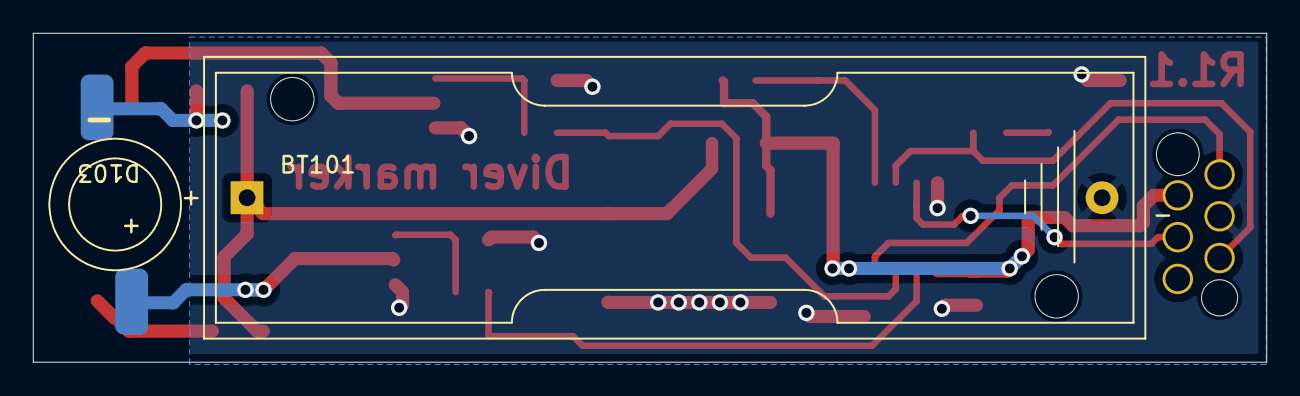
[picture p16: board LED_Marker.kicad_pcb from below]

Board: 2 copper layers, 75.0 x 20.0 mm, 26 parts (2 on the bottom side), 16 nets.

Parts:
BT101: Keystone 2460; BatteryHolder_Keystone_2460_1xAA
C105: 100nF; C_0805_2012Metric_Pad1.18x1.45mm_HandSolder
C107, C108: 100µF/16V; CP_Elec_6.3x5.8
D101: BAV16W; D_SOD-123
D103: LB-P200B2C-H, blue; LPB200XX
D104: LB-P200G3C-H, green; LPB200XX
IC101: PIC16LF15313; SSOP-8_3.9x5.05mm_P1.27mm
J101: SKEDD6; SKEDD-6
Q100, Q101: BST-52; SOT-89-3_Handsoldering
R101, R106: 10K; R_0805_2012Metric_Pad1.20x1.40mm_HandSolder
R102, R109, R110: 1K; R_0805_2012Metric_Pad1.20x1.40mm_HandSolder
R103, R107: 2,2; R_1206_3216Metric_Pad1.30x1.75mm_HandSolder
R104, R108: 100K; R_0805_2012Metric_Pad1.20x1.40mm_HandSolder
SW101: MK15-C2; Meder MK15-C-2
TP101, TP102, TP103, TP104, TP106: TestPoint; TestPoint_Pad_D1.5mm

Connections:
+BATT: BT101.1 (+), C108.1, D101.2 (A), R103.1, R107.1
/A_D103: D103.2 (A), R103.2
/A_D104: D104.2 (A), R107.2
/BQ100: Q100.1 (B), R104.1, R110.1
/BQ101: Q101.1 (B), R108.1, R109.1
/DEBUG: R102.2, TP106.1
/ICSPCLK: IC101.6 (RA1/ICSPCLK), J101.5 (PGC), R102.1
/ICSPDAT: IC101.7 (RA0/ICSPDAT), J101.4 (PGD)
/K_D013: D103.1 (K), Q100.2 (C)
/K_D104: D104.1 (K), Q101.2 (C)
/MCLR!: IC101.4 (MCLR!/RA3), J101.1 (MCLR!), R106.2
/PWR_MCU: C105.1, C107.1, D101.1 (K), IC101.1 (VDD), J101.2 (+5V), R101.1, R106.1, TP101.1
/Reed_In: IC101.5 (RA2), R101.2, SW101.2
BlueOn: IC101.2 (RA5), R110.2, TP102.1
GND: BT101.2 (-), C105.2, C107.2, C108.2, IC101.8 (VSS), J101.3 (GND), Q100.3 (E), Q101.3 (E), R104.2, R108.2, SW101.1, TP104.1
GreenOn: IC101.3 (RA4), R109.2, TP103.1

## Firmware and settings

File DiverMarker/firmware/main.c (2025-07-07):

/* -----------------------------------------------------------------------------
 *
 * Firmware for DiverMarker
 * Autor: Jürgen Eggeling
 * First version 05.2025
 * 
 * Functional description (basic functions):
 * -----------------------------------------
 * The system is activated from sleep by a falling edge of RA.2
 * On RA.2 there is a reed contact active low; activated by the user
 * 
 * While the reed contact is acitvated the system performs these actions:
 * 
 * 1. Wait for a specific time
 * 2. Switch the green LED on for a specific time
 * 3. Wait again a short time (with no LED activated)
 * 4. Switch the red LED on for a specific time
 * 5. Restart the cycle (goto 1)
 * 
 * If the user removes the magnet (RA.2 goes high) the system will enter 
 * sleep mode gain. This is applicable after the minimum blink cycle count
 * Refer next chapter for details.
 * 
 * Functional descriptin (extended functions):
 * -------------------------------------------
 * 
 * Minimum blink cycle count:
 * If the system is activated one there is a minimum blink count in place
 * This helps to avoid flicker and is the base for the power control
 * 
 * Power control of the LEDs:
 * If the minimum blink count is not reached a reed high => low => high
 * cycle increments the power state from Min => Medium => High
 * The power state controls a PWM to modulate the LED intensity.
 *  
 * -------------------------------------------------------------------------- */
#include "mcc_generated_files/system/system.h"

// -----------------------------------------------------------------------------
// Some defines to make code more readable 
// -----------------------------------------------------------------------------
#define FirstOffTime          500u                // for faster user feed back
#define NormalOffTime         2000u               // pause time blink cycle
#define WaitBetween           300u                // between green and red
#define MinOnCycles           5u                  // min cycle count limit
#define GreenOnTime           50u                 // time LED is on
#define RedOnTime             50u                 // dito

#define LoadBlinkTimer(T_u16) {SwTimer_u16=T_u16;}
#define BlinkTimerElapsed     0==SwTimer_u16

#define ReedIsOff             (0 != ReedIn_GetValue())
#define ReedIsOn              (0 == ReedIn_GetValue())
#define MinOnCyclesActive     (0 != MinOnCycles_u08) 
#define MinOnCyclesElapsed    (0 == MinOnCycles_u08)

// -----------------------------------------------------------------------------
// module globale variables and flags 
// -----------------------------------------------------------------------------
static uint8_t  TimerFlag_u08     = 0;              // 1 = timer isr occured
static uint8_t  GreenIsOnFlag_u08 = 0;              // signal for ISR to control
static uint8_t  RedIsOnFlag_u08   = 0;              // physical outputs in PWM
static uint8_t  MinOnCycles_u08   = MinOnCycles+1;  // +1 because of -- first
static uint8_t  WaitReedOnFlag_u8 = 0;              // Edge power mid => high
static uint16_t SwTimer_u16       = 0;              // only one SW timer var
static uint16_t OffTime_u16       = FirstOffTime;   // pause time is variable  

typedef enum 
{
  Blink_Init,
  Blink_WaitOffTime,
  Blink_GreenIsOn,
  Blink_WaitBetweenGreenAndRed,
  Blink_RedIsOn
} BlinkFSM_t;
static BlinkFSM_t BlinkFSM = Blink_Init;

typedef enum 
{
  Power_Low,
  Power_Medium,
  Power_High
} PowerFSM_t;
static PowerFSM_t PowerFSM = Power_Low;

// Coding area from here -------------------------------------------------------

// -----------------------------------------------------------------------------
// The timer 0 interrupt service routine iperforms two tasks:
// - Set the flag for the main routine to handle all functions necessary 
// -----------------------------------------------------------------------------
void MyTmr0(void)
{  
  TimerFlag_u08 = 1;                      // flag set for main() 
}

// -----------------------------------------------------------------------------
// The Perform_LedPWM is in charge to generate PWM signals for the LEDs
// The function is coupled to the state of the Power FSM!
// There are also two helper functions here to make code more readble
// -----------------------------------------------------------------------------
void SetActiveLedsOn(void)                  // helper function for PerformSwPWM
{
  if (GreenIsOnFlag_u08) GreenOn_SetHigh(); // green on only if active
  if (RedIsOnFlag_u08) RedOn_SetHigh();     // red dito
}

void SetLedsOff(void)                       // helper function for PerformSwPWM
{
  GreenOn_SetLow();                         // first green
  RedOn_SetLow();                           // then red
}

void Perform_LedPWM(void)
{
  static uint8_t PWMCnt = 0;                // helper to generate PWM

  if (!GreenIsOnFlag_u08) GreenOn_SetLow(); // switch off all inactive LEDs
  if (!RedIsOnFlag_u08)   RedOn_SetLow();   //   first green, then red
  switch (PowerFSM)                         // perform software PWM for LEDs
  {
    case Power_Low:                         // @Low: Leds active if PWMCnt = 0
      if (0==PWMCnt) SetActiveLedsOn();     // check for counter content = 0
      else SetLedsOff(); 
      break;
      
    case Power_Medium:                      // @Medium: Leds active if PWMCnt = 0
      if (2>PWMCnt) SetActiveLedsOn();      // check for counter content = 1 or 2
      else SetLedsOff(); 
      break;
      
    case Power_High:                        // @High: Leds active all the time 
      SetActiveLedsOn();                    // no check for counter content = 1 or 2
      break;
  }
  PWMCnt++;                                 // increment counter for PWM generation
  if (3 == PWMCnt) PWMCnt = 0;              // count runs from 0 to 2 only  
}

// -----------------------------------------------------------------------------
// The function HandlePowerOff switches off the product if:
// - the minimium cycle count is elapsed AND 
// - the reed contact is inactive
// -----------------------------------------------------------------------------
static void HandlePowerOff()      // Power off if requested by the user
{
  if (ReedIsOff && MinOnCyclesElapsed)   
  {                               
    // power off request valid => prepare sleep
    TMR0_Stop();                  // disable timer (avoid wakeup by timer Int)
    GIE    = 0;                   // real interrupt is not necessary for wakeup
    PORTA;                        // dummy read before clear flags
    IOCAF  = 0;                   // clear interrupt change flags from port RA
    IOCAN2 = 1;                   // enable wakeup by falling edge on RA2
    IOCIE  = 1;                   // enable IO change interrupt module
    SLEEP();                      // stop the system exactly here 
    NOP();                        // proposed to do that after sleep ..
    
    // reed wake up occured => restart the system    
    IOCAN2 = 0;                   // disable interrupt by falling edge on RA2
    IOCIE  = 0;                   // disable IO interrupt module
    IOCAF  = 0;                   // clear interrupt change flags from port RA
    GIE    = 1;                   // enable interrupt system again
    TMR0_Start();                 // enable timer again for basic functionality
    
    // Releoad some variables necessary for restart
    MinOnCycles_u08   = MinOnCycles;  // restart to enable power control 
    WaitReedOnFlag_u8 = 0;            // clear the flag for edge detection   
    OffTime_u16       = FirstOffTime; // restart with short off period
    PowerFSM          = Power_Low;    // restart in power low mode
  }
}

// -----------------------------------------------------------------------------
// The blink FSM is in charge to perform all the basic functionality of the
// product; eg. it controls the blinking cycle of the LEDs
// -----------------------------------------------------------------------------
void Perform_BlinkFSM(void)
{
  switch (BlinkFSM) 
  {
    case Blink_Init:
      if (MinOnCyclesActive)              // count the cycles
        MinOnCycles_u08--;                // to ensure a minimum on time
      LoadBlinkTimer(OffTime_u16);        // cycle starts with the off time  
      BlinkFSM = Blink_WaitOffTime;       // go to the wait state "off"
      break;
    
    case Blink_WaitOffTime:               // Cycle part 1: All LEDs are off
      HandlePowerOff();                   // user power off request?
      if (BlinkTimerElapsed)
      {
        GreenIsOnFlag_u08 = 1;            // flag to ISR to power green LED
        LoadBlinkTimer(GreenOnTime);
        BlinkFSM = Blink_GreenIsOn;
      }
      break;
    
    case Blink_GreenIsOn:                 // Cycle part 2: green is on
      if (BlinkTimerElapsed)
      {
        GreenIsOnFlag_u08 = 0;            // flag to ISR to unpower green LED
        LoadBlinkTimer(WaitBetween);        
        BlinkFSM = Blink_WaitBetweenGreenAndRed;
      }
      break;
    
    case Blink_WaitBetweenGreenAndRed:    // Cycle part 3 = all off again
      if (BlinkTimerElapsed)
      {
        RedIsOnFlag_u08 = 1;              // flag to ISR to power red LED
        LoadBlinkTimer(RedOnTime);        
        BlinkFSM = Blink_RedIsOn;
      }
      break;
      
    case Blink_RedIsOn:                   // Cycle part 4: Red is on
      if (BlinkTimerElapsed)
      {
        RedIsOnFlag_u08 = 0;              // flag to ISR to unpower red LED
        BlinkFSM = Blink_Init;
      }
      break;
    
    default: 
      BlinkFSM =  Blink_Init;    
  }    
  OffTime_u16 = NormalOffTime;            // Off time longer after cycle 1...
}

// -----------------------------------------------------------------------------
// The Power FSM is in place to control the power modes requested by the user.
// -----------------------------------------------------------------------------
void Perform_PowerFSM(void)
{
  switch (PowerFSM) 
  {
    case Power_Low:                         // min cycle still active AND
    if (MinOnCyclesActive && ReedIsOff)     // and user power request?
      {
        MinOnCycles_u08   = MinOnCycles;    // restart the min cycle
        WaitReedOnFlag_u8 = 1;              // set flag for next state 
        PowerFSM          = Power_Medium;   // and now in medium state
      }         
      break;

    case Power_Medium:                      // entry from Power_low, reed may still low!
      if (WaitReedOnFlag_u8)                // flag still set?
      {
        if (ReedIsOn)                       // reset flag in case of 
          WaitReedOnFlag_u8 = 0;            // reed is active again
      }
      else                                  // from here "normal" operation
      {
        if (ReedIsOff && MinOnCyclesActive) // request if both are true
          PowerFSM = Power_High;            // and now in high state                   
      }
      break;

    case Power_High:                        // high state = final state;
      PowerFSM = Power_High;                // .. only for debugging
      break;                                // to enable breakpoints
    
    default:
      PowerFSM = Power_Low;
  }
}

// -----------------------------------------------------------------------------
// Classic short main function
// -----------------------------------------------------------------------------
int main(void)
{
  SYSTEM_Initialize();                    // Call mcc generated files once
  TMR0_OverflowCallbackRegister(MyTmr0);  // hook to own function for timer 0   
  INTERRUPT_GlobalInterruptEnable();      // Enable the Global Interrupts     
  INTERRUPT_PeripheralInterruptEnable();  // Enable the Peripheral Interrupts  
  TMR0_Start();                           // Start the 1ms timer
  while(1)                                // endless loop frome here 
  {
    if (0 != TimerFlag_u08)               // one ms elapsed?
    {    
      DebugOut_SetHigh();
      TimerFlag_u08 = 0;                  // yes, reset the flag
      if (0!=SwTimer_u16) SwTimer_u16--;  // currently one timer is enough

      Perform_LedPWM();                   // perform SW PWM for the LEDs
      Perform_PowerFSM();                 // call the power control FSM
      Perform_BlinkFSM();                 // call the blink generator
      DebugOut_SetLow();
    }
  }    
}
// End of code area ------------------------------------------------------------

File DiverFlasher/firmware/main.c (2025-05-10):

// Diver flasher main module
// ----------------------------------------------------------------------------
#include "mcc_generated_files/system/system.h"

// ----------------------------------------------------------------------------
// debug definitions
// ----------------------------------------------------------------------------
// if enable the ISR will switch on/off the debug output while active
//#define MeasureTmr0

// ----------------------------------------------------------------------------
// module globale defines, typedefs and variables
// ----------------------------------------------------------------------------

// other macros to make code more readable
#define TicsPerMs     25u                 // 25 * 40µs = 1ms
#define LEDOntTime    50u                 // LED on for 50ms
#define LEDOffTime    950u                // while developement LED period = 1s
#define TargetCurrent 730                 // .. a little bit below 750mA
#define T2PRLoadInit  150u                // control value start up value (+6µs)
#define T2PRLoadMin   80u                 // 80 is about 10 + 6µs = 16µs
#define T2PRLoadMax   200u                // 200 is about 25 + 6µs = 31µs
#define MinOnCycles   3u                  // min on cycle count to avoid flicker
#define REED_IS_OFF   0!=Reed_GetValue()  // Reed switch is low acitve 

// type definitions 
typedef enum 
{
  Init,                                   // set up some vars
  PrepareCycle,                           // start pulse on
  PulseOn,                                // LEDs are on, wait for timer
  PulseOff                                // LEDs are off, wait for timer
} MainFSM_t;

// Variables
static int16_t    ActualCurrent_s16;    // current measured in mA
static int16_t    DeviationCurrent_s16; // Deviation = Current - Target
static uint8_t    T2PRLoad_u8;          // calculated reload value for pulse
static uint8_t    MsTimerOccured_u8;    // flag 1ms timer
static uint8_t    MsTimer_u8;           // helper counter for 1m timer
static uint8_t    BoosterActive_u8;     // control pulse output on/off
static uint8_t    MinOnCycles_u08;      // minimum count of cycles after PO
static uint16_t   SWTimerPeriod_u16;    // SW timer to control the LED period
static MainFSM_t  MainFSM = Init;       // the main FSM for behaviour control

// ----------------------------------------------------------------------------
// Timer callback area
// ----------------------------------------------------------------------------
// Main40µs timeout => handle the switch output
static void MyTmr0(void)
{
  #ifdef MeasureTmr0
    Debug_SetHigh();
  #endif      
  // Basic pulse functionality only if enabled by the main function
  if (0 != BoosterActive_u8)
  {
    // Measure current and calculate a new pulse width
    // VREF=1,024V, Shunt=1Ohm => 10 bit result is mA
    ActualCurrent_s16 = (int16_t) ADC_GetConversionResult();
    ADC_StartConversion();                    // start next AD
    
    // generate new control value, based on deviation current - target
    if (0 < ActualCurrent_s16-TargetCurrent)  // acutal current too high?
    {                                         // yes, current is too high
      if (T2PRLoadMin <= T2PRLoad_u8)         // check pulse minimum  
        T2PRLoad_u8--;                        // reduce pulse width
    }
    else                                      // current too low       
    {  
      if (T2PRLoadMax >= T2PRLoad_u8)         // check pulse maximum
        T2PRLoad_u8++;                        // increment pulse width
    }
    
    // Start a new output pulse 
    Switch_SetHigh();                         // start the pulse
    T2PR = T2PRLoad_u8;                       // load HW timer with period
    TMR2_Start();                             // and prepare pulse stop
  }
  if (0 == MsTimer_u8)                // handle the 1m time for the scheduler
  {
    MsTimer_u8 = TicsPerMs;           // Reload timer for one ms tic
    MsTimerOccured_u8 = 1;            // and set the flag for the main function
  }
  MsTimer_u8--;
  #ifdef MeasureTmr0
    Debug_SetLow();
  #endif 
}

// Pulse timer timeout => switch off the pulse
static void MyTmr2()
{
  Switch_SetLow();    
}

// ----------------------------------------------------------------------------
// other module functions
// ----------------------------------------------------------------------------
static void StartStopBooster(uint8_t Control_u8)
{
  INTERRUPT_GlobalInterruptDisable();   // Make the function atomic
  BoosterActive_u8 = Control_u8;        // set variable to control ISR
  T2PRLoad_u8 = T2PRLoadInit;           // load start value for pulse timer
  INTERRUPT_GlobalInterruptEnable();    // enable the global interrupts again
}

// ----------------------------------------------------------------------------
static void DoSWTimer()
{
  if (0!=SWTimerPeriod_u16) SWTimerPeriod_u16--;
}

// ----------------------------------------------------------------------------
static void HandlePowerOff()
{
  if ((REED_IS_OFF) &&             // user switch off request?  
     (0 == MinOnCycles_u08))       // and minimum on cycles zero 
  {                             
    // prepare sleep
    TMR0_Stop();                  // disable timer (avoid wakeup by timer Int)
    TMR2_Stop();
    GIE    = 0;                   // real interrupt is not necessary for wakeup
    PORTA;                        // dummy read before clear flags
    IOCAF  = 0;                   // clear interrupt change flags from port RA
    IOCAN2 = 1;                   // enable wakeup by falling edge on RA2
    IOCIE  = 1;                   // enable IO change interrupt module
    SLEEP();                      // stop the system exactly here 
    NOP();                        // proposed to do that after sleep ..
    
    // restart the system    
    IOCAN2 = 0;                   // disable interrupt by falling edge on RA2
    IOCIE  = 0;                   // disable IO interrupt module
    IOCAF  = 0;                   // clear interrupt change flags from port RA
    GIE    = 1;                   // enable interrupt system again
    TMR0_Start();                 // enable timer again for basic functionality
    MinOnCycles_u08 = MinOnCycles;
  }
}
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

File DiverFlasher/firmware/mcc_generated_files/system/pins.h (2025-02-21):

/**
 * Generated Pins header File
 * 
 * @file pins.h
 * 
 * @defgroup  pinsdriver Pins Driver
 * 
 * @brief This is generated driver header for pins. 
 *        This header file provides APIs for all pins selected in the GUI.
 *
 * @version Driver Version  3.0.0
*/

/*
© [2025] Microchip Technology Inc. and its subsidiaries.

    Subject to your compliance with these terms, you may use Microchip 
    software and any derivatives exclusively with Microchip products. 
    You are responsible for complying with 3rd party license terms  
    applicable to your use of 3rd party software (including open source  
    software) that may accompany Microchip software. SOFTWARE IS ?AS IS.? 
    NO WARRANTIES, WHETHER EXPRESS, IMPLIED OR STATUTORY, APPLY TO THIS 
    SOFTWARE, INCLUDING ANY IMPLIED WARRANTIES OF NON-INFRINGEMENT,  
    MERCHANTABILITY, OR FITNESS FOR A PARTICULAR PURPOSE. IN NO EVENT 
    WILL MICROCHIP BE LIABLE FOR ANY INDIRECT, SPECIAL, PUNITIVE, 
    INCIDENTAL OR CONSEQUENTIAL LOSS, DAMAGE, COST OR EXPENSE OF ANY 
    KIND WHATSOEVER RELATED TO THE SOFTWARE, HOWEVER CAUSED, EVEN IF 
    MICROCHIP HAS BEEN ADVISED OF THE POSSIBILITY OR THE DAMAGES ARE 
    FORESEEABLE. TO THE FULLEST EXTENT ALLOWED BY LAW, MICROCHIP?S 
    TOTAL LIABILITY ON ALL CLAIMS RELATED TO THE SOFTWARE WILL NOT 
    EXCEED AMOUNT OF FEES, IF ANY, YOU PAID DIRECTLY TO MICROCHIP FOR 
    THIS SOFTWARE.
*/

#ifndef PINS_H
#define PINS_H

#include <xc.h>

#define INPUT   1
#define OUTPUT  0

#define HIGH    1
#define LOW     0

#define ANALOG      1
#define DIGITAL     0

#define PULL_UP_ENABLED      1
#define PULL_UP_DISABLED     0

// get/set IO_RA0 aliases
#define IO_RA0_TRIS                 TRISAbits.TRISA0
#define IO_RA0_LAT                  LATAbits.LATA0
#define IO_RA0_PORT                 PORTAbits.RA0
#define IO_RA0_WPU                  WPUAbits.WPUA0
#define IO_RA0_OD                   ODCONAbits.ODCA0
#define IO_RA0_ANS                  ANSELAbits.ANSA0
#define IO_RA0_SetHigh()            do { LATAbits.LATA0 = 1; } while(0)
#define IO_RA0_SetLow()             do { LATAbits.LATA0 = 0; } while(0)
#define IO_RA0_Toggle()             do { LATAbits.LATA0 = ~LATAbits.LATA0; } while(0)
#define IO_RA0_GetValue()           PORTAbits.RA0
#define IO_RA0_SetDigitalInput()    do { TRISAbits.TRISA0 = 1; } while(0)
#define IO_RA0_SetDigitalOutput()   do { TRISAbits.TRISA0 = 0; } while(0)
#define IO_RA0_SetPullup()          do { WPUAbits.WPUA0 = 1; } while(0)
#define IO_RA0_ResetPullup()        do { WPUAbits.WPUA0 = 0; } while(0)
#define IO_RA0_SetPushPull()        do { ODCONAbits.ODCA0 = 0; } while(0)
#define IO_RA0_SetOpenDrain()       do { ODCONAbits.ODCA0 = 1; } while(0)
#define IO_RA0_SetAnalogMode()      do { ANSELAbits.ANSA0 = 1; } while(0)
#define IO_RA0_SetDigitalMode()     do { ANSELAbits.ANSA0 = 0; } while(0)
// get/set IO_RA1 aliases
#define Debug_TRIS                 TRISAbits.TRISA1
#define Debug_LAT                  LATAbits.LATA1
#define Debug_PORT                 PORTAbits.RA1
#define Debug_WPU                  WPUAbits.WPUA1
#define Debug_OD                   ODCONAbits.ODCA1
#define Debug_ANS                  ANSELAbits.ANSA1
#define Debug_SetHigh()            do { LATAbits.LATA1 = 1; } while(0)
#define Debug_SetLow()             do { LATAbits.LATA1 = 0; } while(0)
#define Debug_Toggle()             do { LATAbits.LATA1 = ~LATAbits.LATA1; } while(0)
#define Debug_GetValue()           PORTAbits.RA1
#define Debug_SetDigitalInput()    do { TRISAbits.TRISA1 = 1; } while(0)
#define Debug_SetDigitalOutput()   do { TRISAbits.TRISA1 = 0; } while(0)
#define Debug_SetPullup()          do { WPUAbits.WPUA1 = 1; } while(0)
#define Debug_ResetPullup()        do { WPUAbits.WPUA1 = 0; } while(0)
#define Debug_SetPushPull()        do { ODCONAbits.ODCA1 = 0; } while(0)
#define Debug_SetOpenDrain()       do { ODCONAbits.ODCA1 = 1; } while(0)
#define Debug_SetAnalogMode()      do { ANSELAbits.ANSA1 = 1; } while(0)
#define Debug_SetDigitalMode()     do { ANSELAbits.ANSA1 = 0; } while(0)
// get/set IO_RA2 aliases
#define Reed_TRIS                 TRISAbits.TRISA2
#define Reed_LAT                  LATAbits.LATA2
#define Reed_PORT                 PORTAbits.RA2
#define Reed_WPU                  WPUAbits.WPUA2
#define Reed_OD                   ODCONAbits.ODCA2
#define Reed_ANS                  ANSELAbits.ANSA2
#define Reed_SetHigh()            do { LATAbits.LATA2 = 1; } while(0)
#define Reed_SetLow()             do { LATAbits.LATA2 = 0; } while(0)
#define Reed_Toggle()             do { LATAbits.LATA2 = ~LATAbits.LATA2; } while(0)
#define Reed_GetValue()           PORTAbits.RA2
#define Reed_SetDigitalInput()    do { TRISAbits.TRISA2 = 1; } while(0)
#define Reed_SetDigitalOutput()   do { TRISAbits.TRISA2 = 0; } while(0)
#define Reed_SetPullup()          do { WPUAbits.WPUA2 = 1; } while(0)
#define Reed_ResetPullup()        do { WPUAbits.WPUA2 = 0; } while(0)
#define Reed_SetPushPull()        do { ODCONAbits.ODCA2 = 0; } while(0)
#define Reed_SetOpenDrain()       do { ODCONAbits.ODCA2 = 1; } while(0)
#define Reed_SetAnalogMode()      do { ANSELAbits.ANSA2 = 1; } while(0)
#define Reed_SetDigitalMode()     do { ANSELAbits.ANSA2 = 0; } while(0)
// get/set IO_RA4 aliases
#define Current_TRIS                 TRISAbits.TRISA4
#define Current_LAT                  LATAbits.LATA4
#define Current_PORT                 PORTAbits.RA4
#define Current_WPU                  WPUAbits.WPUA4
#define Current_OD                   ODCONAbits.ODCA4
#define Current_ANS                  ANSELAbits.ANSA4
#define Current_SetHigh()            do { LATAbits.LATA4 = 1; } while(0)
#define Current_SetLow()             do { LATAbits.LATA4 = 0; } while(0)
#define Current_Toggle()             do { LATAbits.LATA4 = ~LATAbits.LATA4; } while(0)
#define Current_GetValue()           PORTAbits.RA4
#define Current_SetDigitalInput()    do { TRISAbits.TRISA4 = 1; } while(0)
#define Current_SetDigitalOutput()   do { TRISAbits.TRISA4 = 0; } while(0)
#define Current_SetPullup()          do { WPUAbits.WPUA4 = 1; } while(0)
#define Current_ResetPullup()        do { WPUAbits.WPUA4 = 0; } while(0)
#define Current_SetPushPull()        do { ODCONAbits.ODCA4 = 0; } while(0)
#define Current_SetOpenDrain()       do { ODCONAbits.ODCA4 = 1; } while(0)
#define Current_SetAnalogMode()      do { ANSELAbits.ANSA4 = 1; } while(0)
#define Current_SetDigitalMode()     do { ANSELAbits.ANSA4 = 0; } while(0)
// get/set IO_RA5 aliases
#define Switch_TRIS                 TRISAbits.TRISA5
#define Switch_LAT                  LATAbits.LATA5
#define Switch_PORT                 PORTAbits.RA5
#define Switch_WPU                  WPUAbits.WPUA5
#define Switch_OD                   ODCONAbits.ODCA5
#define Switch_ANS                  ANSELAbits.ANSA5
#define Switch_SetHigh()            do { LATAbits.LATA5 = 1; } while(0)
#define Switch_SetLow()             do { LATAbits.LATA5 = 0; } while(0)
#define Switch_Toggle()             do { LATAbits.LATA5 = ~LATAbits.LATA5; } while(0)
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

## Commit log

2024-12-14 Initial commit to add existing files and folders to the empty repository
    [#Frame_A4_hoch.dxf, 2024.08.15 - Reichelt.xlsx, Berechnungen, Bauteile & Bestellliste.xlsx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]
2024-12-18 Inter mediate check in
    HW: is working; LED current propably to low
    SW: Basic functions are working.
    System enters sleep; wakeup not working
    Switch handling for manual on/off not implemented
    [LED_Flasher.kicad_pcb, LED_Flasher.kicad_sch]
2024-12-18 Sleep / Wakeup now working
    Auto power off still set to one minute (for easy debugging)
    Next todo: Implement user power off
2024-12-18 First working version of the software
    Reed switch handling implemented
    - Reed activated = flasher running
    - Reed deactivated = flasher enter sleep
    If flasher is activated for 90 minutes it will enter auto power off.
2024-12-26 Information regaring inductor and diode added
    [Bost-Regler-Vergleich.xlsx]
2024-12-26 Document with issues first prototype added. Word / German
2025-01-03 Simulation folder added
    A simulation for a more powerful booster circuit was added.
2025-01-06 New datasheets and simulations added. Target is to improve the power of the booster circuit of the diver flasher.
    [Berechnungen, Bauteile & Bestellliste.xlsx, LED_Flasher.kicad_sch]
2025-01-15 Started with version 1.1 of the dive flasher PCB. 1.0 => old too weak booster 1.1 => new hopefully more powerful booster
    [LED_Flasher.kicad_pcb, LED_Flasher.kicad_sch]
2025-02-09 Start with next version "home brew" boost converter
    [LED_Flasher.kicad_pcb]
2025-02-19 Firmware folder diver flasher renamed Software new generated with melody framework
    [LED_Flasher.kicad_pcb, LED_Flasher.kicad_sch]
2025-02-21 New structure for the diver marker. Ready: Pulse generation Tested on desk only: basic I regulation of pulse width Application: 50ms on, 950ms off, not power up/down yet
2025-02-21 PCB diver flasher restored
    [LED_Flasher.kicad_pcb, LED_Flasher.kicad_sch]
2025-03-03 Update to KiCAD 9
    [LED_Flasher.kicad_pcb, LED_Flasher.kicad_sch]
2025-03-09 Old PC (v1) removed Latest changes for current schematic routed. Almost ready DRC outstanding.
    [LED_Flasher.kicad_pcb, LED_Flasher.kicad_sch]
2025-03-09 Project reorganised: - Outdate and backup files removed - diver flasher and diver marker moved to separate folders
    [#Frame_A4_hoch.dxf, Bohrschablone.dxf, Bost-Regler-Vergleich.xlsx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]
2025-03-28 New pcb design with KiCAD 9 started. Old eagle design moved to archive folder.
    [Diver_Marker_AA.brd, Diver_Marker_AA.sch, LED_Marker.kicad_pcb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]
2025-04-04 DRC errors removed, finished
    [LED_Flasher.kicad_pcb, LED_Flasher.kicad_sch]
2025-04-09 Routing PCB diver marker started; almost ready but a least of open drc errors.
    [LED_Marker.kicad_pcb, LED_Marker.kicad_sch]
2025-04-09 pcb finished errors almost removed
    [LED_Marker.kicad_pcb]
2025-04-10 Unused datasheets removed Keystone 1024 tested but not used because of space requirements. Still THT version used on board.
    [LED_Marker.kicad_pcb, LED_Marker.kicad_sch]
2025-04-10 Updates on Backup folder
    [LED_Flasher.kicad_pcb]
2025-04-11 Distributors for all componentes added.
    [LED_Marker.kicad_sch]
2025-04-12 Working on BON
    [LED_Marker.kicad_sch]
2025-04-14 Working on PCB documentation
    [LED_Marker.kicad_pcb]
2025-04-27 Component placement optimisation. No functional changes
    [LED_Marker.kicad_pcb]
2025-04-27 PCB sizes added on layer user 1
    [LED_Marker.kicad_pcb]
2025-04-27 Production data with JLCPCB plugin generated
    [LED_Flasher.kicad_pcb, bom.csv, designators.csv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]
2025-05-04 Side view of the PCB on measurement layer added.
    [LED_Flasher.kicad_pcb]
2025-05-04 Side View on Measurment layer added
    [LED_Marker.kicad_pcb]
2025-05-07 Setup firmware within MCC, coding startet; timer not running correct yet.
    [main.c, pins.h]
2025-05-07 PCB informations added
    [LED_Marker.kicad_pcb]
2025-05-09 Work on firmware / HW - activate sleep (not finished yet) - To Do list for next version PCB added
2025-05-09 Work on HW and SW
    - To Do list for next version of pcb
    - Start coding firmware (currently issue with PA.5)
    [main.c]
2025-05-09 PortA.5 issue fixed (External oszillator was not disabled; Clock setup)
    [main.c]
2025-05-09 Working on sleep mode Currently no wakeup
2025-05-10 Sleep and wakeup are working now. On time is minimum 3 cycles.
    ToDo: Check current consumption to validate HW and SW for battery life time.
2025-05-10 Sleep and wakeup is working now. Minimum on cycles is 3 cycles
    => at this moment same user logic as diver flasher!
    Next steps:
    - Implement 2 or 3 different lightning levels (SW)
    - Validate current consumption to validate HW and SW
2025-05-10 Ruhestrom hinzugefügt (50µA)
    [LED_Flasher.kicad_sch]
2025-05-10 Minor changes: - LED blue replaced by red one (curret is on blue too low) - LED resistors changed from 2.2Ohm to 1Ohm - quiescent current added (about 25µA)
    [LED_Marker.kicad_sch]
2025-05-10 Two power modes added.
    Cycle on, off, on agwain within the first min cycle switches to high power
2025-05-11 Intensity method changed from time (not good) to a software PWM (much better).
2025-05-12 Timing und current check. No functional changes
2025-05-18 Platineneigenschaften und Lagenaufbau au PCB-Sheet hinzugefügt.
    [LED_Flasher.kicad_pcb]
2025-05-18 Materialrecherche Amazon hinzugefügt.
    [Grundsatzüberlegungen Gehäuse für DiverMarker und Diverflasher.xlsx]
2025-05-24 Weitere Daten zu Gehäuseinformationen hinzugefügt
    [Grundsatzüberlegungen Gehäuse für DiverMarker und Diverflasher.xlsx]
2025-05-24 Document folder added.
    [DiverFlasher Berechnung Batterielebensdauer.xlsx]
2025-05-24 - Archiv removed - Document folder added
    [DiverMarker Berechnung Batterielebensdauer.xlsx]
2025-05-24 Battery calculation update
    [DiverFlasher Berechnung Batterielebensdauer.xlsx]
2025-05-31 Drawing of bottom housing part added.
    [Rohrboden.dxf]
2025-05-31 Rohrbodenzeichnung vervollständigt.
    [Rohrboden.dxf]
2025-06-28 Calculation update regarding last measurements
    [DiverMarker Berechnung Batterielebensdauer.xlsx]
2025-06-28 Table with current measurements added.
    [LED_Marker.kicad_sch]
2025-06-30 Mechanical BOM added
    [Mechanical BOM DF.xlsx, Mechanical BOM DM.xlsx]
